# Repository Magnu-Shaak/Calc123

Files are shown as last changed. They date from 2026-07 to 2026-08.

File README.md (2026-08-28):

# Numpad
Making a Numpad accessory that also works as a stand-alone calculator!

Features:
- Numberpad (0-9, 4 operations,"=", ".")
    + Has a built in Local Calculator that displays on the OLED
- Custom Shortcuts Layer
- Displays Layer on OLED
    + Use it yourself: Info at [https://github.com/Magnu-Shaak/Calc123/blob/main/oled_extention.md](url)

3d render in Onshape



## BOM
Also available at [https://github.com/Magnu-Shaak/Calc123/blob/main/bom.csv](url)
| Item | Quantity | Listed Price | Total Cost | Link | Source | Notes | |
|---|---|---|---|---|---|---|---|
| PCB (5 piece) | 1 | 4 | 5.76 | | JLC PCB | Together with another order, paying with JLC account (Saves on shipping) | |
| XIAO RP2040 | 1 | 4.9 | 4.9 | https://www.digikey.com/en/products/detail/seeed-technology-co-ltd/102010428/14672129 | DigiKey | | |
| Diodes | 16 | 0.8 | 0.8 | https://www.digikey.com/en/products/detail/diotec-semiconductor/1N4148/13164514 | DigiKey | | |
| "Switches | | | | | | | |
| (32 piece)" | 1 | 10.99 | 10.99 | https://www.amazon.com/gp/aw/d/B09NNN4XPB | Amazon | Cheaper than AliExpress | |
| 0.91 in. OLED (2 piece) | 1 | 5.99 | 0 | https://www.amazon.com/Dorhea-Display-Module-SSD1306-3-3V-5V/dp/B08F9F8BYB | Amazon | Cheaper than Digikey with manu. Shipping. Can pay for myself | |
| | | | | | | | |
| Soldering Iron (Pinecil)* | 1 | 39.99 | 39.99 | https://www.amazon.com/PINECIL-Smart-Mini-Portable-Soldering/dp/B096X6SG13 | Amazon | Cheapest Adjustable Soldering Iron | |
| Solder (0.5 oz) | 1 | 2.97 | 2.97 | https://www.digikey.com/en/products/detail/chip-quik-inc/NCSW-031-0-5OZ/13531391 | DigiKey | 63/37 tin-lead solder (0.031"") | |
| De-soldering Braid | 1 | 2.59 | 2.59 | https://www.digikey.com/en/products/detail/chip-quik-inc/SOLDERWICK2-0/14636561 | DigiKey | 0.08" | 5 foot" |
| Soldering Stand & Sponge  | 1 | 3.28 | 3.28 | https://www.digikey.com/en/products/detail/soldered-electronics/555024/29271457 | Digikey | Soldered Electronics: ""Soldering Iron Stand"" | |
| | | | | | | | |
| Case | 1 | 3.5 | 0 | | Local Library | $0.05 per gram, will pay for myself | |
| Key Caps (10 piece) | 2 | 9.9 | 9.9 | https://www.digikey.com/en/products/detail/adafruit-industries-llc/5039/14313478 | DigiKey | Adafruit, cheaper than singles | |
| | | | | | | | |
| M2 screw (16mm) | 5 | 0.65 | 0.65 | http://digikey.com/en/products/detail/essentra-components/50M020040P016B/26883690 | DigiKey | Essentra Components, 5th one was 1 cent | |
| M2 heatset Inserts | 5 | 1.09 | 1.09 | https://www.digikey.com/en/products/detail/tri-star-industries-inc/M20X157C/13535373  | DigiKey | Edit 3d model, 5th one was 1 cent | |
| | | | | | | | |
| DigiKey: Shipping and Tax | 8 (32) | 9.09 | 10.45 | https://www.digikey.com/ordering/shoppingcart | DigiKey | Shipping with USPS Ground Advantage (4.99) | |
| Amazon: Shipping and Tax  | s | 3.82 | 3.82 | | Amazon | Free shipping with prime | |
| | | | | | | | |
| Total | 71 | 103.56 | 97.19 | | | | |

## Demo links

PCB Demo [Link](https://kicanvas.org/?repo=https%3A%2F%2Fgithub.com%2FMagnu-Shaak%2FCalc123%2Ftree%2Fmain%2FPCB)

OnShape Demo [Link](https://cad.onshape.com/documents/84cb760b87cada0103a9576e/w/b2684d83a2c2c7ea59db64e2/e/a0996dbd1c890850b6caf7a1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)
(click on search bar and hit enter again to load properly)

Code is visible under the Firmware folder

## Asembly

BOM (Bill of Materials) - above, or at [https://github.com/Magnu-Shaak/Calc123/blob/main/BOM.csv](url)

0 - Gather your Materials (PCB, Case parts, Devboard, and a usb-c to [something] cable to connect to your computer

1 - Download Circuit Python (v9.2.9) from circuitpython.org for the microcontroller [here](https://adafruit-circuit-python.s3.amazonaws.com)

2 - Download KMK (as .zip) from the kmk_firmware repo on github [here](https://github.com/KMKfw/kmk_firmware)

3 - Download the dependency files from the circuitpython.org/libraries (for the circuit python 9.x version) or from [here](https://github.com/adafruit/Adafruit_CircuitPython_Bundle/releases/download/20260729/adafruit-circuitpython-bundle-9.x-mpy-20260729.zip)

4 - Download "main.py" and "oled_extension.py" from this repo. They are stored under the "Production" Folder

5 - Mount the microcontroller to your computer
    -Hold the 'B' (boot) bottom
    -Connect it to the computer via a usb-c to [anything on your computer] cable
    -Release the 'B' bottom

6 - Upload Circuit Python's .u2f file onto the microcontroller
    -It Should self eject and reconnect as CIRCUITPY

7 - From the kmk_firmware zip file, Upload the "KMK" folder and boot.py into the root of the CIRCUITPY drive

8.5 - If there is not already a "lib" folder in the root of your CIRCUITPY drive, make one

9 - From the circuit python bundle zip file, Upload the "adafruit_bus_device" and "adafruit_display_text" folders and "adafruit_displayio_ssd1306" file into the lib folder of your CIRCUITPY drive

10 - Eject your CIRCUITPY drive, and disconnect your microcontroller from your computer.

11 - Solder your XIAO RP 2040 devboard and 16 diodes (make sure they are oriented correctly) to the back of your PCB

12 - Place the Top Plate onto the front of your PCB, and align it with the mx key switch positions

13 - Solder the Key switches to the PCB on the back. The plate should be supported by the mx switches when you flip back over

14 - Install the Heatset Inserts to the bottom of your Case

15 - Place the PCB and Top Plate onto the supports in the case

16 - Screw the plate onto your PCB

16.5 - Add the Key Caps onto the MX Switches

17 - Slide in the Custom Insert
16 - Connect your Macropad to the computer and begin using it.

## All Images

  Schematic (Controller)



  Schematic (Key Array)



  PCB Design (KiCad)



  PCB Render (KiCad)
  


  Case (Onshape)



  USB Cutout



  Custom Insert (Onshape)



  Code is under Firmware/main.py and Firmware/oled_extension.py

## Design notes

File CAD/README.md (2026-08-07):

In this Folder (CAD):
- Assembled Model Files

In Production Folder:
- Individual Part Files
- 3d printing aranged file (All Parts)

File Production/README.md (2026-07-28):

Schematic:
- gerbers.zip

Case:
- Numpad - Bottom.step
- Numpad - Custom_Insert.step
- Numpad - Top.step

Firmware:
- main.py
- oled_extension.py

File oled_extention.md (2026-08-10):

# OLED extension
This is my OLED extension I made in CircuitPy that is compatable to use with KMK. 
I Don't believe anyone will see this, but if you are, use the oled_layer_extension.py file, under the Firmware folder. The oled_extension is configured to the board I am using, and my own oled modifications

## List of Supported features below:

Event Updating:
- Layer Changes

Display Chips:
- SSD 1306

## Configure
```python
# main.py or code.py
from oled_extension import init_oled                # Import

# Name this whatever, just be consistent with the name when you call the  init_oled function
layer_names_map = {  
    0: "Numpad",       # Map the text displayed to layer index
    1: "Functions",    # If no text is defined, it defaults to "Layer x"
}

# Input your entries for each of the feilds. If no entry is added, some feilds have default values set
init_oled(keyboard, layer_names_map, scl_pin, sda_pin, display_hight=32, display_width=128, display_address=0x3C)

# For Example:
init_oled(keyboard, layer_names_map, board.D5, board.D4, 64, 128, 0x3C)
```
## Other
Comment on this repo if you want me to add anythin. Image support and Mod Layers as events will be added promptly upon request.

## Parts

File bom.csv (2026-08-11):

Item | Quantity | Total Price | Link | Source | Notes (TAX NOT INCLUDED)
PCB (5 peice) | 1 | $7.64 | https://www.pcbway.com/QuickOrderOnline.aspx | PCB way | From Actual Checkout page (Shipping DDP with Global Direct Shipping)
Devboard | 1 | $9.99 | https://www.amazon.com/Pre-Soldered-Microcontroller-MicroPython-CircuitPython-Interfaces/dp/B09NNVNW7M | Amazon | XIAO rp2040
Cherry MX Switches (10 peice) | 2 | $11.14 | https://www.aliexpress.us/item/3256807705085808.html | AliExpress Choice | "Limit 1 per color:1 white | 1 silver"
0.91 in. OLED (5 peice) | 1 | $0.99 | https://www.aliexpress.us/item/3256808453793642.html | AliExpress Choice | Lowest Price Option*
White Keycaps (50 peice; white) | 1 | $0.99 | https://www.aliexpress.us/item/3256810533781399.html | AliExpress Choice | Lowest Price Option*
M3x16mm Screws (100 peice) | 1 | $0.99 | https://www.aliexpress.us/item/2255800046543591.html | AliExpress Choice | Lowest Price Option*
M3x5mmx4mm heatset Inserts (100 peice) | 1 | $0.99 | https://www.aliexpress.us/item/2255800046543591.html | AliExpress Choice | Lowest Price Option*
Case | 1 | $3.50 | Local Library | Local Library | $0.05 per gram
Soldering Irorn | 1 | $39.99 | https://www.amazon.com/PINECIL-Smart-Mini-Portable-Soldering/dp/B096X6SG13 | Amazon | Pinecil: Cheapest heat adjustable soldering Iron
Soldering Stand & Sponge | 1 | $4.99 | https://www.microcenter.com/product/659033/Mini-soldering_stand_with_sponge | Micro Center | Eclipse Enterprice Mini
Solder (50 g) | 1 | $8.99 | https://www.amazon.com/MAIYUM-63-37-Solder-Electrical-Soldering/dp/B075WB98FJ?th=1 | Amazon | "MAIYUM 63-37 Tin-Lead Rosin Core Solder Wire 0.8mm | 50g g"
Solder Wick | 1 | $12.98 | https://www.homedepot.com/pep/Weller-Desoldering-Wick-Wire-2-5mm-0-1-in-1-6m-63-in-WLWIRDESW/335954017 | Home Depot | "Weller Brand | Cheapest Currently Avalible"
Total Cost | 1 |  | https://excel.cloud.microsoft/en-us/ | Microsoft Exel
*Footnotes |  |  | *Lowest Price Option. Smaller quantities only avalible for same price
 |  |  | Also Tax is only Included for PCB way
1N4148 THT Diodes (100 peice) | 1 | $0.99 | https://www.aliexpress.us/item/3256809192784213.html | AliExpress Choice | Lowest Price Option*

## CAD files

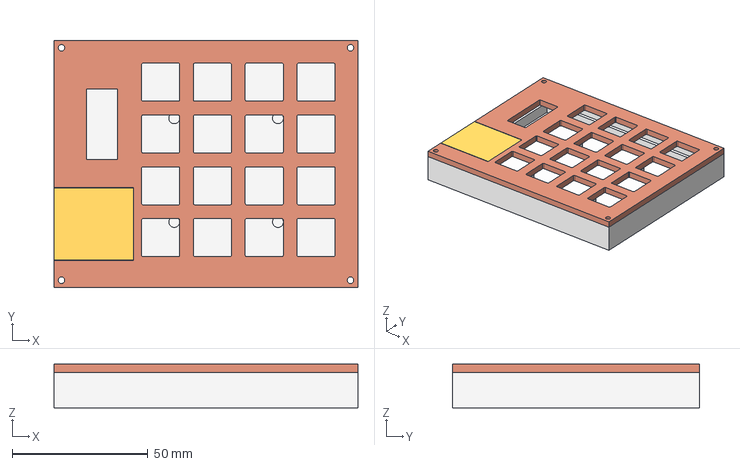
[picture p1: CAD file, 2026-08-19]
CAD/Assembled.step
111.8 x 91.0 x 16.0 mm

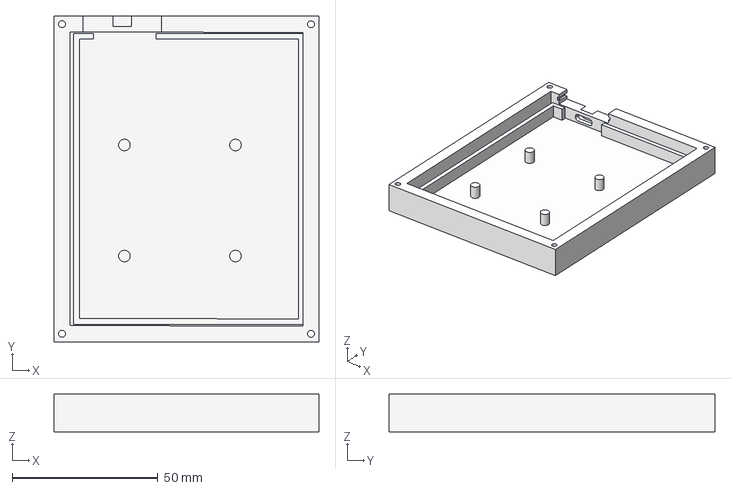
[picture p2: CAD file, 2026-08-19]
Production/Individual_Parts/Printing - Main_Case.step
91.0 x 111.8 x 13.0 mm

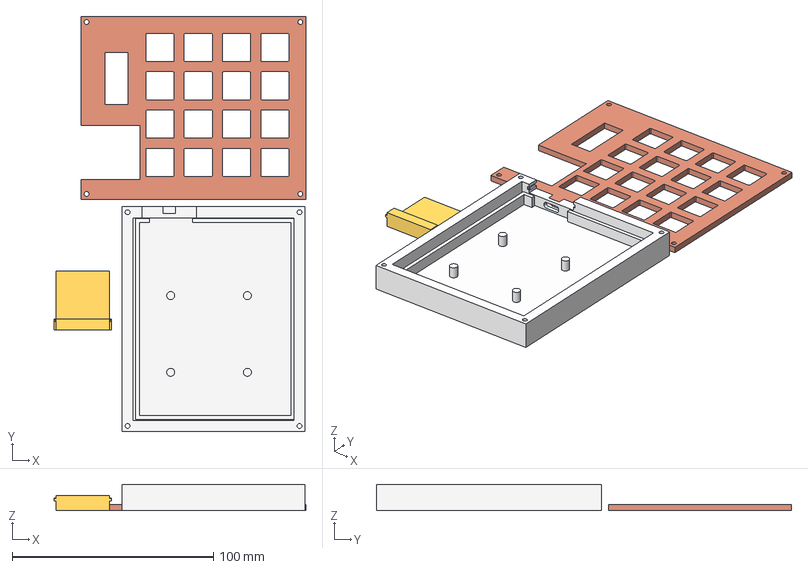
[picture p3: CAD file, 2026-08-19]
Production/Printing.step
125.2 x 206.4 x 13.0 mm

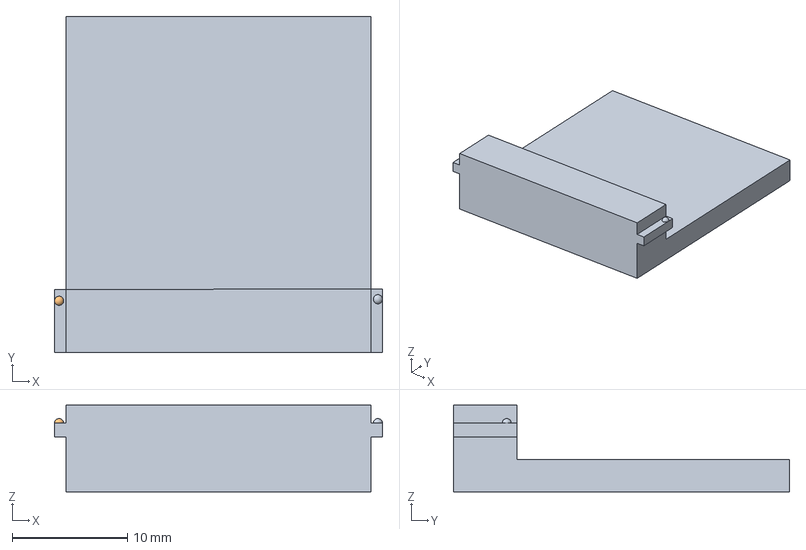
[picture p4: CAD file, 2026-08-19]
Production/Individual_Parts/Printing - Custom_Insert.step
28.5 x 29.2 x 7.54 mm

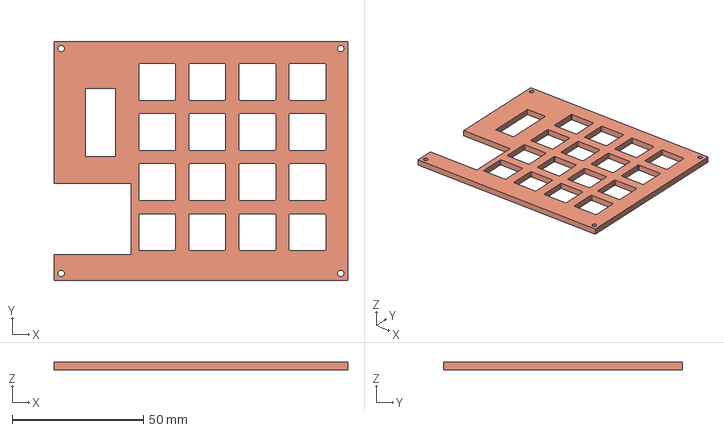
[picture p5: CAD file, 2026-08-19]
Production/Individual_Parts/Printing - Top.step
111.8 x 91.0 x 3.00 mm

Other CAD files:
CAD/Assembled.stl
Production/Individual_Parts/Printing - Custom_Insert.stl
Production/Individual_Parts/Printing - Main_Case.stl
Production/Individual_Parts/Printing - Top.stl
Production/Printing.stl

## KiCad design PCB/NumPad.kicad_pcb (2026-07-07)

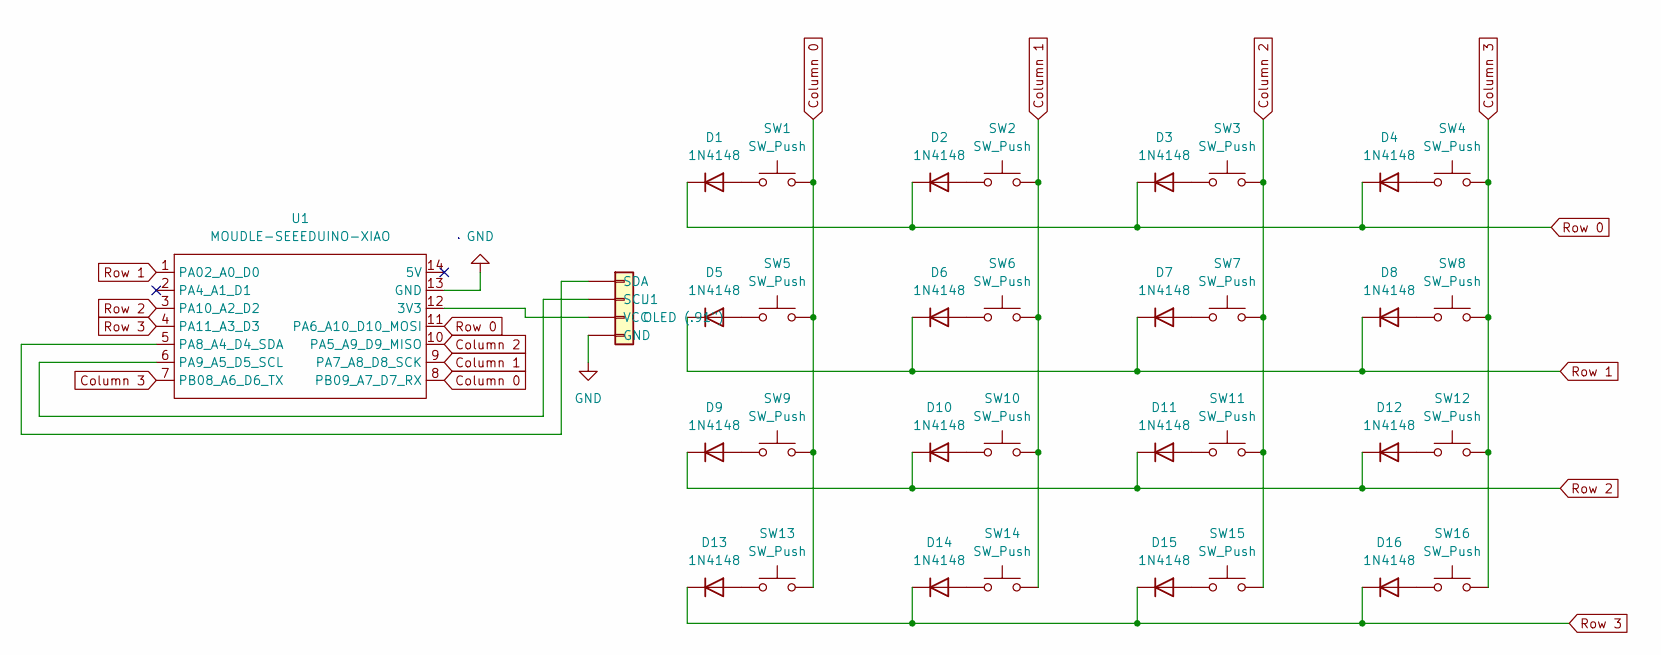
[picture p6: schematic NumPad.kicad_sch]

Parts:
D1, D2, D3, D4, D5, D6, D7, D8, D9, D10, D11, D12, D13, D14, D15, D16: 1N4148; D_DO-35_SOD27_P7.62mm_Horizontal
J1: OLED (.91"); 0.91_inch_OLED
SW1, SW2, SW3, SW4, SW5, SW6, SW7, SW8, SW9, SW10, SW11, SW12, SW13, SW14, SW15, SW16: SW_Push; SW_Cherry_MX_1.00u_PCB(1)
U1: MOUDLE-SEEEDUINO-XIAO; XIAO-Generic-Hybrid-14P-2.54-21X17.8MM

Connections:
Column 0: SW1.2, SW5.2, SW9.2, SW13.2, U1.8 (PB09_A7_D7_RX)
Column 1: SW2.2, SW6.2, SW10.2, SW14.2, U1.9 (PA7_A8_D8_SCK)
Column 2: SW3.2, SW7.2, SW11.2, SW15.2, U1.10 (PA5_A9_D9_MISO)
Column 3: SW4.2, SW8.2, SW12.2, SW16.2, U1.7 (PB08_A6_D6_TX)
GND: J1.1 (GND), U1.13 (GND)
unnamed: D1.2 (A), SW1.1
unnamed: D2.2 (A), SW2.1
unnamed: D3.2 (A), SW3.1
unnamed: D4.2 (A), SW4.1
unnamed: D5.2 (A), SW5.1
unnamed: D6.2 (A), SW6.1
unnamed: D7.2 (A), SW7.1
unnamed: D8.2 (A), SW8.1
unnamed: D9.2 (A), SW9.1
unnamed: D10.2 (A), SW10.1
unnamed: D11.2 (A), SW11.1
unnamed: D12.2 (A), SW12.1
unnamed: D13.2 (A), SW13.1
unnamed: D14.2 (A), SW14.1
unnamed: D15.2 (A), SW15.1
unnamed: D16.2 (A), SW16.1
unnamed: J1.3 (SCL), U1.6 (PA9_A5_D5_SCL)
unnamed: J1.4 (SDA), U1.5 (PA8_A4_D4_SDA)
unnamed: J1.2 (VCC), U1.12 (3V3)
Row 0: D1.1 (K), D2.1 (K), D3.1 (K), D4.1 (K), U1.11 (PA6_A10_D10_MOSI)
Row 1: D5.1 (K), D6.1 (K), D7.1 (K), D8.1 (K), U1.1 (PA02_A0_D0)
Row 2: D9.1 (K), D10.1 (K), D11.1 (K), D12.1 (K), U1.3 (PA10_A2_D2)
Row 3: D13.1 (K), D14.1 (K), D15.1 (K), D16.1 (K), U1.4 (PA11_A3_D3)

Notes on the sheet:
GND

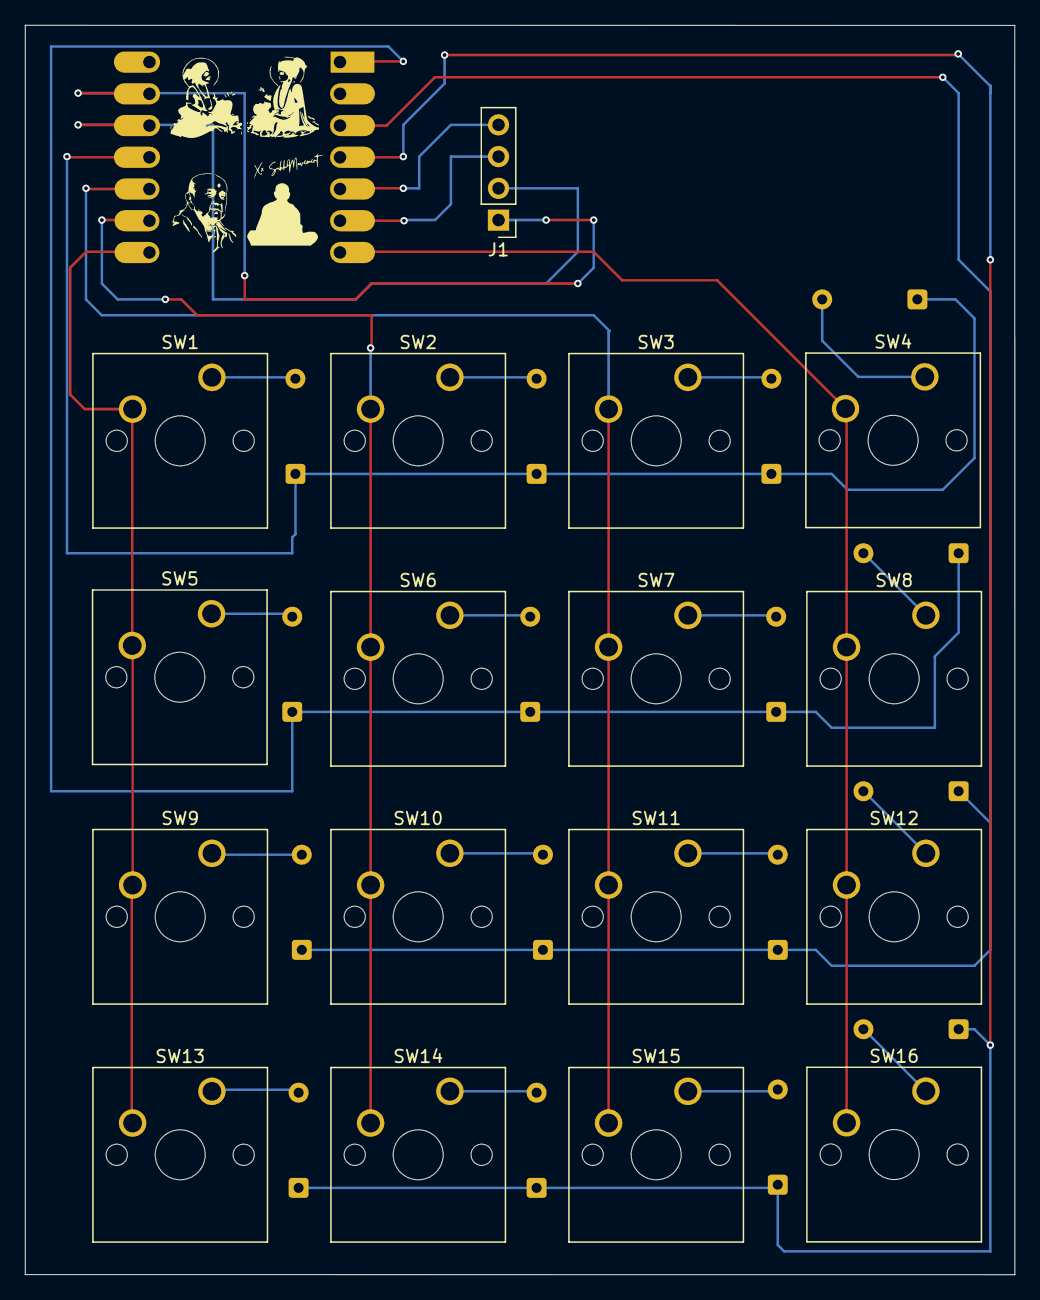
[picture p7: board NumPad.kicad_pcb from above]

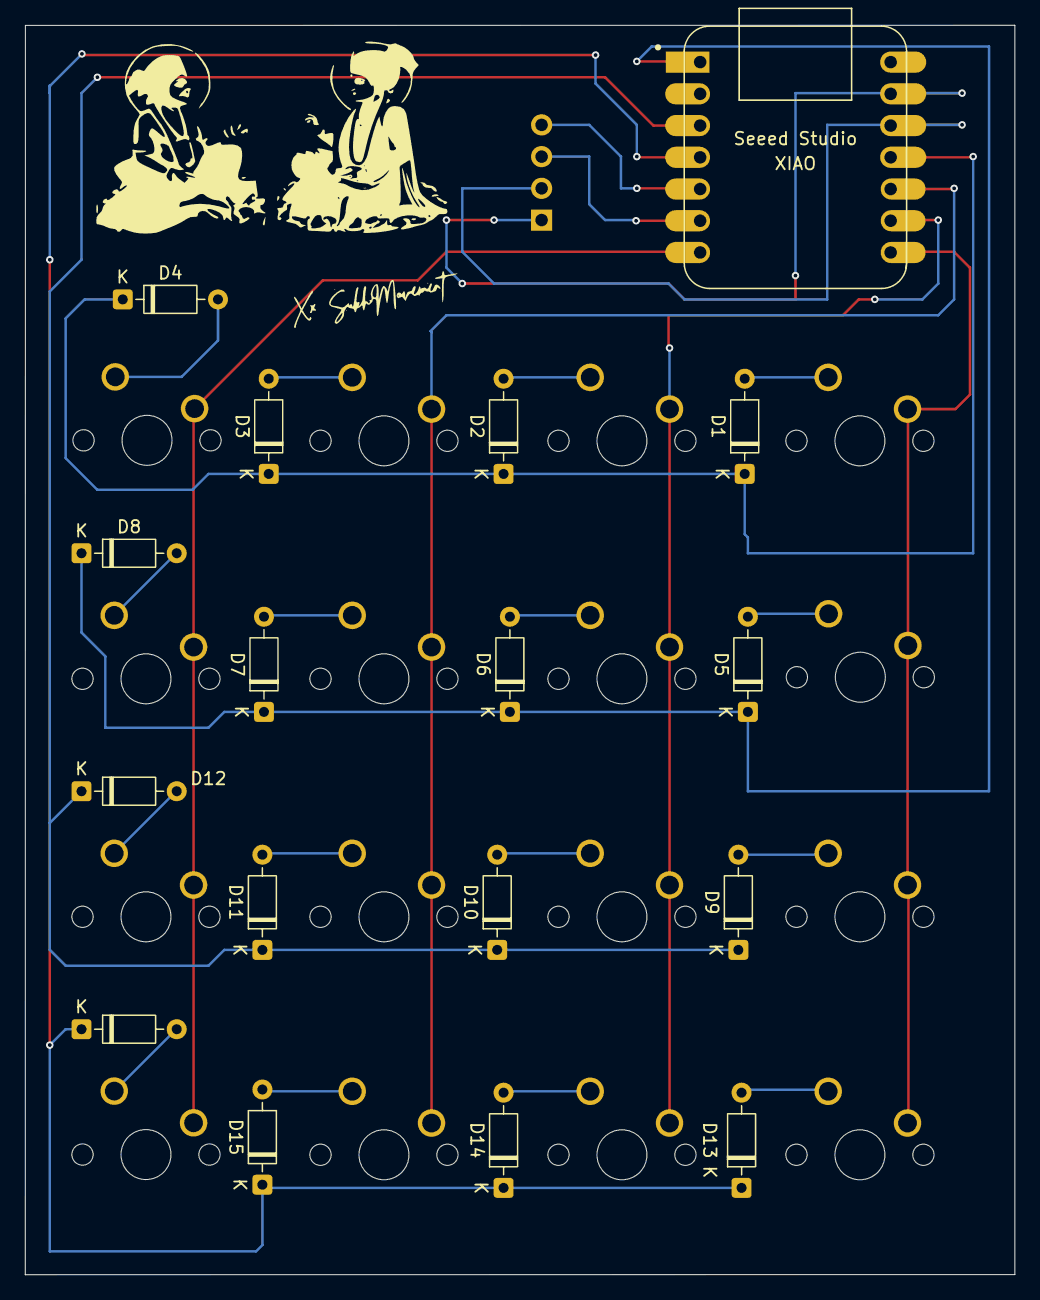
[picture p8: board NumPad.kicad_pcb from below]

Board: 2 copper layers, 79.2 x 100.0 mm, 34 parts (17 on the bottom side), 28 nets.

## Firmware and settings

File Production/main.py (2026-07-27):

import board                                        # Board
from oled_extension import init_oled                # Oled Display
from kmk.kmk_keyboard import KMKKeyboard            # Keys
from kmk.keys import KC, Key
from kmk.scanners import DiodeOrientation
from kmk.modules.layers import Layers               # Layer toggle
from kmk.modules.combos import Combos, Chord, Sequence
from kmk.modules.dynamic_sequences import DynamicSequences      #Dynamic Sequences
from kmk.modules.tapdance import TapDance
from kmk.extensions.media_keys import MediaKeys

#Initialize
keyboard = KMKKeyboard()
combos = Combos()
tapdance = TapDance()
keyboard.modules.append(Layers())
keyboard.modules.append(combos)
keyboard.modules.append(DynamicSequences())
keyboard.extensions.append(MediaKeys())
keyboard.modules.append(tapdance)
tapdance.tap_time = 750

# OLED Display
layer_names_map = {
    0: "Numpad",
    1: "Functions",
}
init_oled (
    keyboard, layer_names_map, board.D5, board.D4, 0x3C, 32, 128
    )

# Local Calculator
import math                     # TO_DO: ADD DOT, CLEAR, BSPACE,
og_process_key = keyboard.process_key

class RemoverKeys(Key):
    def __init__(self, key, **kwargs):
        super().__init__(**kwargs)
        self.name = self.name
    def __str__(self): return self.name
    def __repr__(self): return self.__str__()

Clear = RemoverKeys("KC.CLEAR")
Backspace = RemoverKeys("KC.BACKSPACE")

keyboard.calc_state = {
    "raw_str": "",
    "answer": "",
    "operator": "",
    "a": "",
    "b": "",
    "op_index": None,
    "is_active": False,
    "negative_numbers": False
}
state = keyboard.calc_state
operator_list = {
    "KC.KP_PLUS": "+",
    "KC.KP_MINUS": "-",
    "KC.KP_ASTERISK": "*",
    "KC.KP_SLASH": "/",
    "KC.CIRCUMFLEX": "**",
    "KC.PERCENT": "%",
    "KC.PIPE": "//",
    }
other_symbols_list = {
    "KC.ENTER": "=",
    "KC.DOT": ".",
    "KC.CLEAR": "",
    "KC.BACKSPACE": "",
}

def clear():
    state["raw_str"] = ""
    state["answer"] = ""
    state["operator"] = ""
    state["a"] = ""
    state["b"] = ""
    state["op_index"] = ""

def running_total(kmk_name):
    if "=" in state["raw_str"]:
        if kmk_name in operator_list:
            if not state["negative_numbers"]: abs(int(state["answer"]))     # If negative numbers mode is off, make negative number into posative, temporary fix
            state["a"] = state["answer"]
            state["raw_str"] = state["answer"]
            state["operator"] = ""
            state["b"] = ""
            state["answer"] = ""

        else: clear()

def calculator(operator, a, b):
    try:
        ans = eval(state["raw_str"])
        return ans
    except Exception:
        if operator == "+":
            return (a + b)
        elif operator == "-":
            return (a - b)
        elif operator == "*":
            return (a * b)
        elif operator == "^":
            return (a ** b)
        elif operator == "/":
            if b == "0": return "Error: Div by 0"
            return (a / b)
        elif operator == "%":
            if b == "0": return "Error: Div by 0"
            return (a % b)
        elif operator == "|":
            if b == "0": return "Error: Div by 0"
            return (a // b)
        else:
            return "Error"

def calc_interpreter(key, is_pressed, coordinate=None):         #Interprites KMK imputs for the calculator function
    if not state["is_active"]:
        return og_process_key(key, is_pressed, coordinate=None)
    
    val = None
    keyboard.modules.layers.activate_layer(0)
    if is_pressed:
        if "Error" in state["raw_str"]: clear()

        kmk_name = str(key)
        running_total(kmk_name)

        if "KC.ENTER" in kmk_name: kmk_name = "KC.ENTER"

        if(
            state["negative_numbers"]           # Is negative number mode active
            and kmk_name == "KC.MINUS"          # Is this a negative sign
            and ((not state["operator"] and not state["a"])# <--- allows 
            or (state["operator"] and not state["b"]))  # Is it a/b and are they fit to be negative num
        ):
            val = "-"
            kmk_name = "KC.UNDERSCORE"

        if "KC.N" in kmk_name:
            val = kmk_name.split("KC.N")[-1]
 #        elif KC.KP in kmk_name:
 #            val = kmk_name.split("KC.KP_")[-1]
        elif kmk_name in operator_list:
            if state["operator"]:                   # Multiple Operater Check
                return None
            else:
                try:                                # If there is no a value, don't count this input
                    temp_a = float(state["a"])
                except Exception:
                    state["raw_str"] = "Error: Invalid_Num. a"
                    return None
                val = operator_list.get(kmk_name)
                state["operator"] = val
                state["op_index"] = len(state["raw_str"])
        elif kmk_name in other_symbols_list:        # Duplicates checks, depends on symbol
            if kmk_name == "KC.Dot":
                # If no operator(so a) and decimal, --OR-- If operator (so b) and  decimal [ie. Invalid Inputs]
                if (not state["operator"] and "." in state["a"]) or (state["operator"] and "." in state["b"]):
                    return None     # Don't add decimal
                pass
            elif kmk_name == "KC.ENTER":    # If "=" alr there and another abt to be entered
                if "=" in state["raw_str"]:
                    return None
                pass
            elif kmk_name == "KC.CLEAR":            # Remover Keys checks 
                clear()
                return None
            elif kmk_name == "KC.BACKSPACE":
                state["raw_str"] = state["raw_str"][:-1]
            else:
                return None
            val = other_symbols_list.get(kmk_name)
    
        else:
            return None

    if val is None: return None
    elif val == "=":                      # Send forward
        if not state["operator"] or state["operator"] not in state["raw_str"]:
            clear()
            return None

        op_index = state["op_index"]
        raw_str = state["raw_str"]
        str_a, operator, str_b = raw_str[:op_index], raw_str[op_index], raw_str[op_index:]
        if not str_b: return None
        a = float(str_a) if "." in str_a else int(str_a)
        b = float(str_b) if "." in str_b else int(str_b)
        result = calculator(operator, a, b)

        if isinstance(result, str) and "Error" in result:
            clear()
            state["raw_str"] = "Error: Calc_Error"
            return None
        
        elif isinstance(result, float) and result.is_integer():
            result = int(result)

        state["answer"] = str(result)
        state["raw_str"] += f" {val} "
        state["raw_str"] += str(result)

        return None

    state["raw_str"] += val
    if state["operator"]:   # and state["operator"] in state["raw_str"]
        op_index = state["op_index"]
        raw_str = state["raw_str"]
        state["a"], state["b"] = raw_str[:op_index], raw_str[op_index:]
    else:
        state["a"] = state["raw_str"]
    
    return None

keyboard.process_key = calc_interpreter

def calc_mode_toggle(key, keyboard, *args):
    state["is_active"] = not state["is_active"]
    return keyboard
def negative_numbers_toggle(key,keyboard, *args):
    state["negative_numbers"] = not state["negative_numbers"]

Calculate_Key = Key(on_press=calc_toggle)
Negative_Mode_Toggle = Key(on_press=negative_numbers_toggle)

# Combos
combos.combos = [
    Chord((KC.KP_DOT, KC.KP_PLUS), KC.TG(1)),      # Toggles
    Chord((KC.KP_VOLD, KC.KP_PLUS), KC.TG(1)),
    Chord((KC.KP_PLUS, KC.KP_MINUS, KC.ASTR, KC.KP_SLASH), KC.TG(0)),
    Chord((KC.KP_PLUS, KC.KP_MINUS), Calculate_Key),
    Chord((KC.KP_PLUS, KC.ASTR), KC.CIRC),           # Operators
    Chord((KC.KP_PLUS, KC.KP_SLASH), KC.PERC),
    Chord((KC.KP_MINUS, KC.KP_SLASH), KC.PIPE),
    Chord((KC.KP_MINUS, KC.Dot), Negative_Mode_Toggle)
]
Record = KC.TD(KC.PLAY_SEQUENCE, KC.RECORD_SEQUENCE(), KC.STOP_SEQUENCE())
Paste = KC.TD(KC.LCTL(KC.V),KC.LCTL(KC.LSFT(KC.V)))

#Keyboard Layout
keyboard.col_pins = (board.D7, board.D8, board.D9, board.D6)        # D7 D8, D9, D6
keyboard.row_pins = (board.D10, board.D0, board.D2, board.D3)       # D10, D0, D2, D3
keyboard.diode_orientation = DiodeOrientation.COL2ROW


keyboard.keymap = [         # Maybe add another layer for Calculator active? 
    [
        KC.N1, KC.N2, KC.N3, KC.KP_PLUS,
        KC.N4, KC.N5, KC.N6, KC.KP_MINUS,
        KC.N7, KC.N8, KC.N9, KC.ASTR,
        KC.N0, KC.KP_DOT, KC.LT(1,KC.ENTER), KC.KP_SLASH,
    ],
    [
        KC.LCTL(KC.C), Paste, KC.LALT(KC.TAB), KC.TRNS,
        KC.LCTL(KC.Z), OLD, Record, KC.TRNS,
    ],
    [KC.LCTL(KC.Y), KC.LCTL(KC.BSLASH), KC.TRNS,
        KC.LCTL(KC.W), KC.LCTL(KC.LSFT(KC.T)), KC.LCTL(KC.T), KC.TRNS,
        KC.VOLU, KC.V
        
    ]
]
#       Copy, Paste, Switch Tap 
#       Undo, Redo, Sp. Format
#       Close, Reopen, New Tab
#       Vol UP, Vol DN, Dynamic

if __name__ == "__main__":
    keyboard.go()

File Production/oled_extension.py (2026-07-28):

import busio
import time
import displayio
import terminalio
import adafruit_displayio_ssd1306
from adafruit_display_text import label
from kmk.extensions import Extension
try:
    from i2cdisplaybus import I2CDisplayBus
except ImportError:
    from displayio import I2cDisplay as I2CDisplayBus

# For Displaying Layer Name
class DisplayManager(Extension):
    def __init__(self, names_dict, display_text, notes_text):
        self.display_text = display_text
        self.names_dict = names_dict
        self.notes_text = notes_text
        self.last_layer = None

    def after_matrix_scan(self, keyboard):
        state = getattr(keyboard, "calc_state", None)
        if state and state["is_active"]:
            current_text = state["raw_str"]
            current_text = current_text[:state["op_index"]] + f" {state['operator']} " + current_text[state["op_index"] + 1:]
            
            if state["a"]:
                notes = "Calc_mode, -Num. ACTV"
            else:
                notes = "Calc_mode"
            

            if (current_text != self.display_text) or (notes != notes_text):
                self.display_text = current_text
            
            return

        active_list = keyboard.active_layers
        current_layer = max(active_list) if active_list else 0
        if current_layer != self.last_layer:
            self.last_layer = current_layer
            layer_name = self.names_dict.get(current_layer, f"LAYER {current_layer}")
            self.display_text.text = layer_name
            self.notes_text = ""

    def on_runtime_init(self, keyboard): pass
    def during_lookahead(self, keyboard, active_layers): pass
    def before_matrix_scan(self, keyboard): pass  
    def before_hid_send(self, keyboard): pass
    def after_hid_send(self, keyboard): pass

def init_oled(keyboard, layer_names_map, scl_pin, sda_pin, display_address=0x3C, display_height=32, display_width=128):
    displayio.release_displays()                    # Reset display

    i2c_bus = busio.I2C(scl_pin, sda_pin)         # Initialize display (D5 - SCL, D4 - SDA)
    display_bus = I2CDisplayBus(i2c_bus, device_address=display_address)
    display = adafruit_displayio_ssd1306.SSD1306(display_bus, width=display_width, height=display_height)
 
    oled_group = displayio.Group()                 # Text to Bitmap engine
    top_active_layer = label.Label(
        terminalio.FONT,
        text="Jai Swaminarayan",
        color=0xFFFFFF,
        scale=1,
        x=0,
        y=12,
     )

    oled_group.append(top_active_layer)
    oled_group.append(calc_notes)

    display.root_group = oled_group
    time.sleep(3.0) 

    keyboard.extensions.append(DisplayManager(layer_names_map, top_active_layer, calc_notes))

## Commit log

2026-07-07 Create CAD Folder
2026-07-07 Make CAD Folder
2026-07-07 Make PCB Folder
2026-07-07 Add PCB files
    Created repo late, so only near-final file vertion
    [NumPad.kicad_pcb, NumPad.kicad_sch]
2026-07-08 Add Case Files
    Add Case File (current version as of making github repo)
    [Calc123_Case_V2.step]
2026-07-09 Add Custom Case Insert
    Rough Insert only, DO NOT expect to be smooth
    [Calc123_Case.step]
2026-07-09 Delete Older File
    Will continuously update same file instead
    [Calc123_Case_V2.step]
2026-07-09 Add Case File V2
    First Complete Case File, as imagined
    [Calc123_Case.step]
2026-07-09 Add lock mechanism for insert
    Should be final vertion
    [Calc123_Case.step]
2026-07-12 Add OLED drivers (ssd1306)
2026-07-14 Organize imports Add Layer Switching
2026-07-14 Define Layer 2 (Shortcuts)
    [main.py]
2026-07-21 Prevented displaying while calc_mode is active
    [main.py]
2026-07-22 Debugged errors left from previose commit
    [main.py]
2026-07-23 Fix delete key Refine Search
    [main.py]
2026-07-28 Add Case Production Files
    [Numpad - Custom_Insert.step, Numpad - Main_Case.step, Numpad - Top.step]
2026-07-28 Rename Files
    [Numpad - Bottom.step]
2026-07-28 Add supports for PCB
    [Part Studio 1 - Custom_Insert.step, Part Studio 1 - Main_Case.step, Part Studio 1 - Top.step]
2026-07-29 Add pcb production files
2026-07-29 Add Assembly Instructions
2026-07-30 Add 3d printing stl files
    [Part Studio 1 - Custom_Insert.stl, Part Studio 1 - Main_Case.stl, Part Studio 1 - Top.stl]
2026-08-07 Corrected ledge supports
    [Part Studio 1 - Custom_Insert.step, Part Studio 1 - Custom_Insert.stl, Part Studio 1 - Main_Case.step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]
2026-08-07 Rename Production/Part Studio 1 - Custom_Insert.step to Production/Individual_Parts/Part Studio 1 - Custom_Insert.step
    [Part Studio 1 - Custom_Insert.step]
2026-08-07 Move for organization
    [Part Studio 1 - Main_Case.stl]
2026-08-07 Rename Production/Part Studio 1 - Custom_Insert.stl to Production/Individual_Parts/Part Studio 1 - Custom_Insert.stl
    [Part Studio 1 - Custom_Insert.stl]
2026-08-07 Organized Files
    [Part Studio 1 - Main_Case.step]
2026-08-19 Add M2 vertion of files
    [Assembled.step, Assembled.stl]
2026-08-28 Add Updated BOM
    [BOM.csv]
2026-08-28 Updated BOM
    [BOM.csv]
